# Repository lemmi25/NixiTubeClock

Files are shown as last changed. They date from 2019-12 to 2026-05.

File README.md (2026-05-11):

# ESP32 NixiTube OTA Clock

<p align="center">
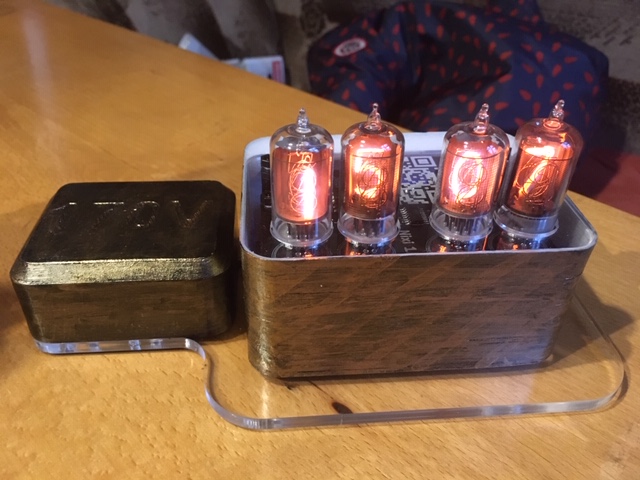
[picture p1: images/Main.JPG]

</p>

## Hardware Profiles

Firmware variants live in src/hardware:

- master_no_rtc.cpp
	- No RTC module
	- Time sync from internet API
	- FreeRTOS tasks (display/buttons and WiFi/OTA)
- rtc_local.cpp
	- DS1307 RTC module
	- Local time from RTC with optional internet sync
	- Power and menu button handling in single-loop runtime

## Tube Types

Tube mapping is selected in include/clock_variant_config.h via config.env:

- ZM1000
- IN4
- DA2000 (numitron)

## Main Configuration

All build-time options are read from config.env by extra_scripts/read_config_env.py.
Each key in config.env becomes a C/C++ define automatically.

Typical minimal setup:

```env
HARDWARE_PROFILE=RTC_LOCAL
TUBE_TYPE=ZM1000

ENABLE_OTA=1
OTA_IP=192.168.10.56
OTA_PASSWORD=nixiclock

WIFI_SSID=YOUR_WIFI_SSID
WIFI_PASSWORD=YOUR_WIFI_PASSWORD
CITY=Europe/Berlin
TIME_API_BASE=https://timeapi.io/api/Time/current/zone?timeZone=
```

## OTA Update

OTA is enabled with ENABLE_OTA=1.

- OTA stays always available after WiFi is connected.
- Flash command:

```bash
./scripts/ota_flash_monitor.sh
```

The script reads OTA_IP, OTA_PASSWORD, OTA_PORT from config.env, builds firmware, uploads over OTA, then opens serial monitor.

## Buttons And LEDs

Current runtime behavior:

- Power button (BTN_ON / GPIO3): toggle hibernate and wake
- Menu button (BTN_MODE / GPIO15): short/long press function handling
- LED brightness level: LED_DIM
	- master_no_rtc currently uses LED_DIM in firmware defaults
	- rtc_local supports LED_DIM from config.env and includes boot LED intro animation

## Build

USB build/upload:

```bash
platformio run -e esp-wrover-kit
```

OTA build/upload environment:

```bash
platformio run -e esp-wrover-kit-ota
```

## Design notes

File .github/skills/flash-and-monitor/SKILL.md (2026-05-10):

---
name: flash-and-monitor
description: 'Build, upload (flash), and monitor NixiTubeClock firmware via PlatformIO. Use when flashing firmware, selecting hardware profile or tube type from config.env, opening serial monitor, and debugging over USB.'
argument-hint: 'Optional: port override, e.g. --upload-port /dev/ttyUSB0'
---

# Flash & Monitor — NixiTubeClock

## When to Use
- Uploading new firmware to the ESP32 clock board
- Opening the serial monitor to watch boot logs or debug output
- Verifying a build before or after flashing
- Verifying the selected hardware profile and tube mapping from config.env

## Config First

Before build/flash, edit `config.env` (create from `config.env.example`):

```env
HARDWARE_PROFILE=MASTER_NO_RTC
TUBE_TYPE=ZM1000
PROVISION_AP_NAME=NixiClockSetup
WIFI_SYNC_SECONDS=3600
MAX_SYNC_FAILS=3
TIME_API_BASE=http://worldtimeapi.org/api/timezone
WIFI_SSID=YOUR_WIFI_SSID
WIFI_PASSWORD=YOUR_WIFI_PASSWORD
CITY=Europe/Berlin
```

**Note:** `TIME_API_BASE` uses a global base URL (no continent prefix). Your `CITY` setting must use "Continent/City" format like "Europe/Berlin", "America/New_York", or "Asia/Tokyo".

**Fast path:** if `FORCE_PROVISIONING=0` in `config.env` and the SSID/password above are valid, the firmware will skip the hotspot and connect directly to WiFi at boot.

## Prerequisites
- [PlatformIO Core](https://docs.platformio.org/en/latest/core/installation/index.html) installed (or use the PlatformIO IDE extension in VS Code)
- ESP32 board connected via USB
- Working directory: project root (where `platformio.ini` lives)

## Manual Boot Mode (Custom PCB)

This PCB has **no auto-reset circuit** (no DTR/RTS → BOOT/EN wiring).  
You must put the ESP32 into download mode manually before every flash:

1. Hold down the **BOOT** button
2. Press and release the **RST** button *(keep BOOT held)*
3. Release the **BOOT** button
4. ESP32 is now in download mode — run the upload command within a few seconds

> `platformio.ini` already has `--before no_reset` so esptool will not try to auto-reset.  
> The flash script (`scripts/flash_and_monitor.sh`) will prompt you to complete these steps before uploading.

## Commands

### 1. Build only
```sh
pio run -e esp-wrover-kit
```

### 2. Build + Upload (flash)
```sh
pio run -e esp-wrover-kit -t upload
```

### 3. Serial monitor (57600 baud, matches `monitor_speed` in platformio.ini)
```sh
pio device monitor --baud 115200
```

### 4. Build, upload, then immediately open serial monitor
```sh
pio run -e esp-wrover-kit -t upload && pio device monitor --baud 115200
```

## Port Troubleshooting

List all connected serial devices:
```sh
pio device list
```

Override the upload port manually:
```sh
pio run -e esp-wrover-kit -t upload --upload-port /dev/ttyUSB0
```

On Linux, if you get a **permission denied** error on the serial port:
```sh
sudo usermod -aG dialout $USER   # then log out and back in
```

## Expected Behavior by Hardware Profile

**MASTER_NO_RTC**
- Connects to WiFi and fetches time from `TIME_API_BASE` + `CITY`
- Displays hour/minute from internet response

**RTC_LOCAL**
- Reads time from DS1307 RTC
- Does not require internet time sync

## Error Conditions

| Serial output | Meaning | What happens next |
|---|---|---|
| `config.env loaded ...` | Build script parsed config values | Confirms selected hardware and tube |
| `Unknown HARDWARE_PROFILE=...` | Invalid profile value in config.env | Build uses no valid profile and fails at compile guard |
| `Unknown TUBE_TYPE=...` | Invalid tube selection in config.env | Build has no matching tube mapping |

See the `debug-clock-hardware` skill for full hardware diagnostics.

## Key Files
- [platformio.ini](../../../platformio.ini) — build environment, script integration, source filter
- [config.env.example](../../../config.env.example) — template for local config
- [extra_scripts/read_config_env.py](../../../extra_scripts/read_config_env.py) — config.env parser
- [src/hardware/master_no_rtc.cpp](../../../src/hardware/master_no_rtc.cpp) — no RTC profile
- [src/hardware/rtc_local.cpp](../../../src/hardware/rtc_local.cpp) — RTC profile

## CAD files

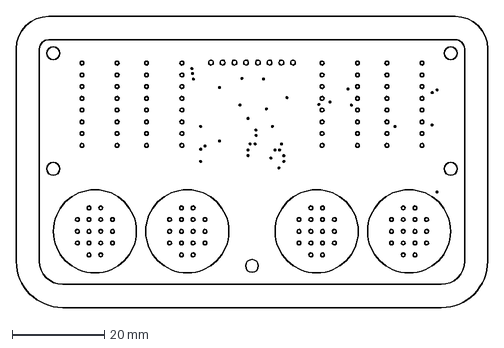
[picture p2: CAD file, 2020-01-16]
Case/nixiTop.dxf
102.0 x 63.0 mm

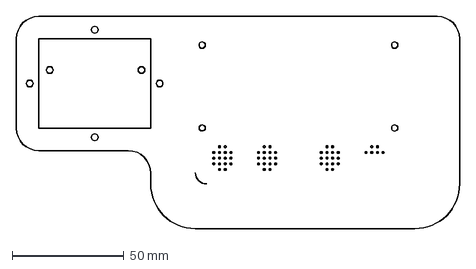
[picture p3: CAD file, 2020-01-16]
Case/nixiBottom.dxf
198.0 x 94.9 mm

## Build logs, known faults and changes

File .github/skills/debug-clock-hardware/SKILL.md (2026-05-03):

---
name: debug-clock-hardware
description: 'Debug all NixiTubeClock hardware variants and modules: no-RTC and RTC profiles, tube mappings (ZM1000/IN4/DA2000), WiFi provisioning AP, shift-register output, RTC wiring, and display behavior.'
argument-hint: 'Optional: describe symptom, e.g. "setup AP not visible", "digits swapped", "RTC loses time", or "wrong tube output"'
---

# Debug Clock Hardware - NixiTubeClock

## When to Use
- Setup hotspot is not visible or web portal does not open
- WiFi credentials are saved but internet sync still fails
- RTC profile does not keep time between sync cycles
- No-RTC profile drifts or stops updating time
- Digits appear swapped or incorrect for your tube type
- DA2000 numitron output is wrong while nixie tubes work
- Display is blank or only partial digits are lit

## Hardware Profiles

Configured in `config.env`:

| Key | Values | Behavior |
|---|---|---|
| `HARDWARE_PROFILE` | `MASTER_NO_RTC`, `RTC_LOCAL` | Selects no-RTC or RTC firmware path |
| `TUBE_TYPE` | `ZM1000`, `IN4`, `DA2000` | Selects segment mapping and numitron mode |

Relevant files:
- [src/hardware/master_no_rtc.cpp](../../../src/hardware/master_no_rtc.cpp)
- [src/hardware/rtc_local.cpp](../../../src/hardware/rtc_local.cpp)
- [include/clock_variant_config.h](../../../include/clock_variant_config.h)
- [src/nixiDriver.cpp](../../../src/nixiDriver.cpp)

## Provisioning AP and Web Portal Checks

Provisioning implementation:
- [src/hardware/clock_provisioning.cpp](../../../src/hardware/clock_provisioning.cpp)
- [include/clock_provisioning.h](../../../include/clock_provisioning.h)

Expected behavior:
1. If config is missing/invalid, ESP opens AP (`PROVISION_AP_NAME`)
2. Connect to AP and open `http://192.168.4.1`
3. Save `ssid`, `password`, `city`
4. Device restarts and uses saved settings

If AP is not visible:
- Verify `PROVISION_AP_NAME` in `config.env`
- Ensure placeholders are not left as real credentials
- Check monitor output for `Entering provisioning mode` and `AP IP`

## RTC Path Diagnostics (`RTC_LOCAL`)

- Confirm DS1307 wiring and I2C lines
- Confirm backup battery polarity and charge
- Verify `rtc.begin()` and `rtc.isrunning()` path at boot
- If internet sync fails repeatedly, device should re-enter provisioning mode

## No-RTC Path Diagnostics (`MASTER_NO_RTC`)

- Device syncs internet time every `WIFI_SYNC_SECONDS` (default 3600)
- Between syncs, display time uses internal millis-based counter
- If sync fails `MAX_SYNC_FAILS` times, provisioning portal should open

## Tube Mapping Diagnostics

Mappings live in:
- [include/clock_variant_config.h](../../../include/clock_variant_config.h)

Quick checks:
- `ZM1000`: straight mapping 1-2-3-4
- `IN4`: swapped first two segments
- `DA2000`: reverse segment ordering and numitron logic

If digits are wrong:
1. Confirm `TUBE_TYPE` in `config.env`
2. Rebuild and verify build output shows selected type
3. If still wrong, check wiring from shift register outputs to tube drivers

## Build/Config Validation Checklist

1. Confirm `config.env` exists and is parsed
2. Confirm `HARDWARE_PROFILE` and `TUBE_TYPE` are valid
3. Confirm pre-script is enabled in `platformio.ini`
4. Rebuild after config changes (`clean` + build)

## Key Files
- [config.env.example](../../../config.env.example)
- [config.env](../../../config.env)
- [platformio.ini](../../../platformio.ini)
- [extra_scripts/read_config_env.py](../../../extra_scripts/read_config_env.py)
- [src/hardware/hardware_profile_guard.cpp](../../../src/hardware/hardware_profile_guard.cpp)

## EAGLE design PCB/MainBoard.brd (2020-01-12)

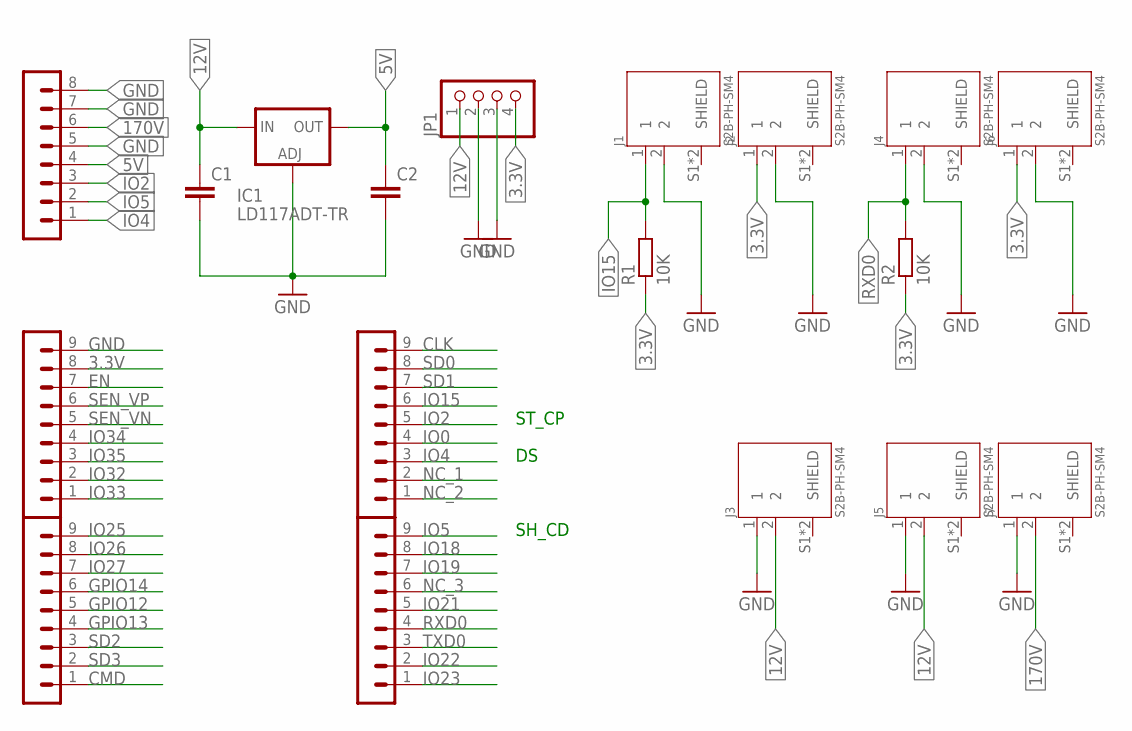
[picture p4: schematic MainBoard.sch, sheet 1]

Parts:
C1, C2: C-EU_1206C1206; C1206
IC1: LD117ADT-TR; DPACK
J1, J2, J3, J4, J5, J6, J7: S2B-PH-SM4; JST_S2B-PH-SM4-TB(LF)(SN)
JP1: PINHD-1X4; 1X04
R1, R2: 10K; R1206
SV1: PINHEADER-1X8; MA08-1
SV2, SV3, SV4, SV5: PINHEADER-1X9; MA09-1

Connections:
3.3V: J2.1, J6.1, JP1.4, R1.1, R2.1, SV2.8
5V: C2.1, IC1.4 (OUT), SV1.4
12V: C1.1, IC1.3 (IN), J3.2, J5.2, JP1.1
170V: J7.2, SV1.6
CLK: SV4.9
CMD: SV3.1
EN: SV2.7
GND: C1.2, C2.2, IC1.1 (ADJ), J1.2, J2.2, J3.1, J4.2, J5.1, J6.2, J7.1, JP1.2, JP1.3, SV1.5, SV1.7, SV1.8, SV2.9
GPIO12: SV3.5
GPIO13: SV3.4
GPIO14: SV3.6
IO0: SV4.4
IO2: SV1.3, SV4.5
IO4: SV1.1, SV4.3
IO5: SV1.2, SV5.9
IO15: J1.1, R1.2, SV4.6
IO18: SV5.8
IO19: SV5.7
IO21: SV5.5
IO22: SV5.2
IO23: SV5.1
IO25: SV3.9
IO26: SV3.8
IO27: SV3.7
IO32: SV2.2
IO33: SV2.1
IO34: SV2.4
IO35: SV2.3
NC_1: SV4.2
NC_2: SV4.1
NC_3: SV5.6
RXD0: J4.1, R2.2, SV5.4
SD0: SV4.8
SD1: SV4.7
SD2: SV3.3
SD3: SV3.2
SEN_VN: SV2.5
SEN_VP: SV2.6
TXD0: SV5.3

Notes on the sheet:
ST_CP
SH_CD

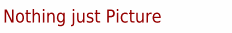
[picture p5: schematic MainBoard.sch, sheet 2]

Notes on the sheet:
Nothing just Picture


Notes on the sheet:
Nothing just Picture

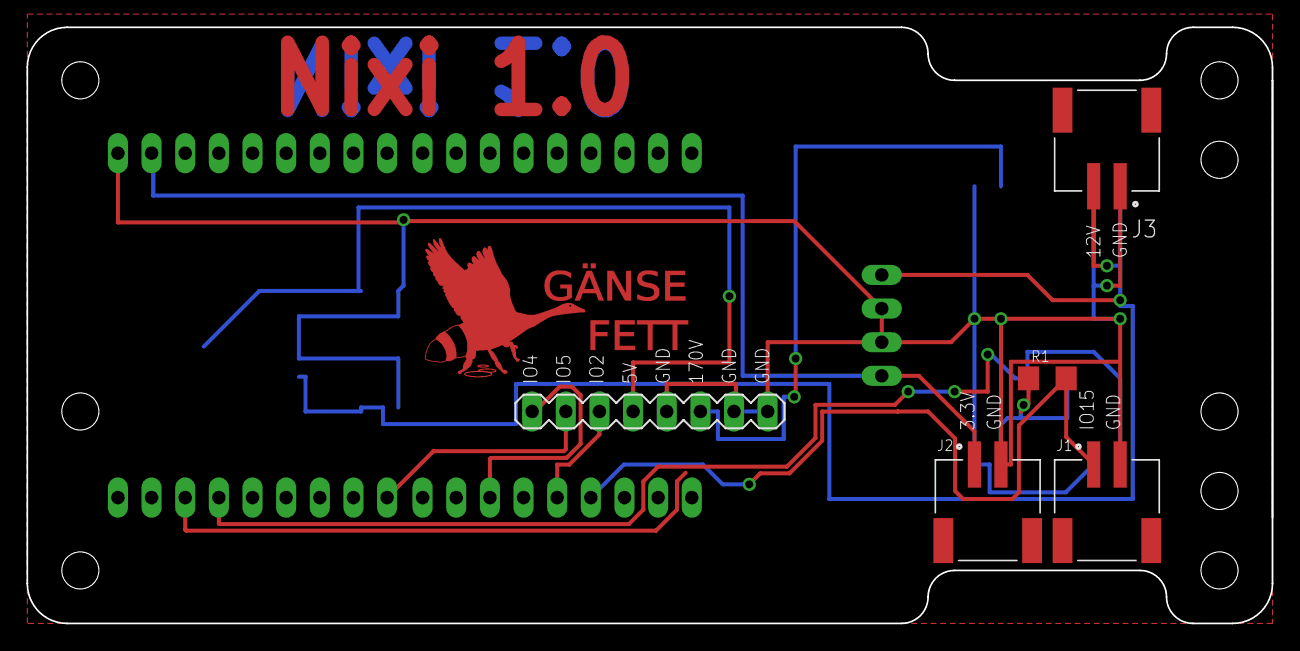
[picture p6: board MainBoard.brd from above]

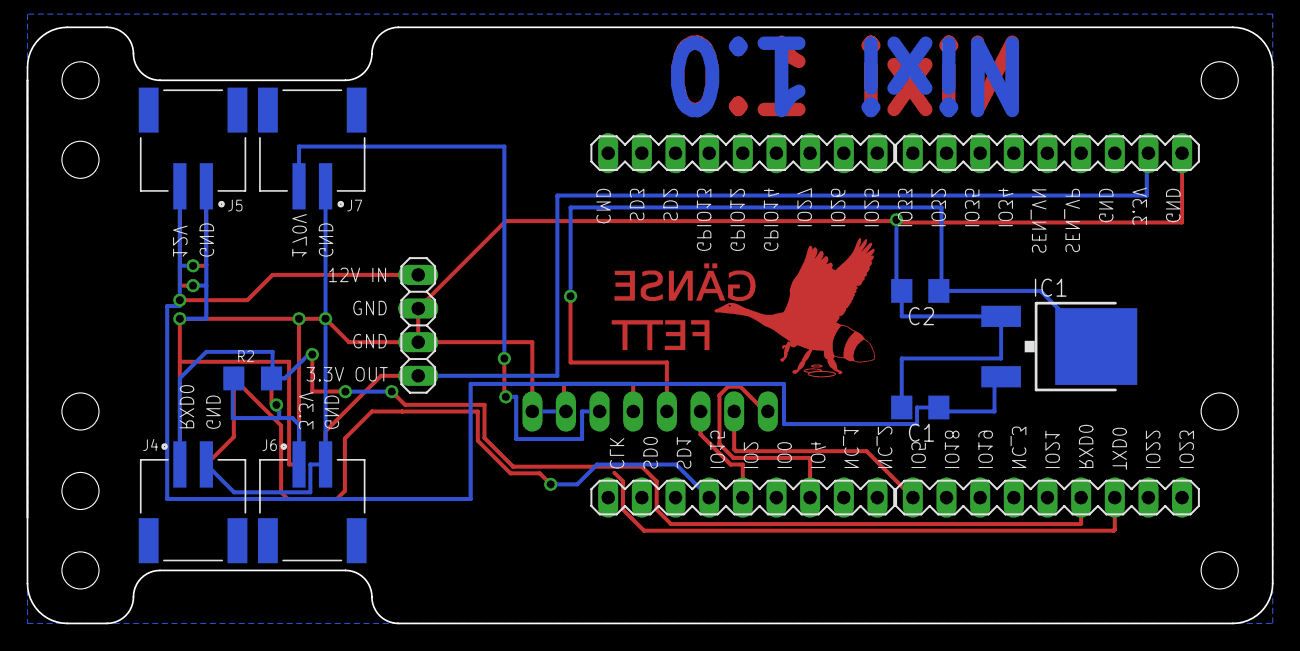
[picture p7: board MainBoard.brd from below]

Board: 2 copper layers, 94.0 x 45.0 mm, 18 parts (13 on the bottom side), 10 nets.

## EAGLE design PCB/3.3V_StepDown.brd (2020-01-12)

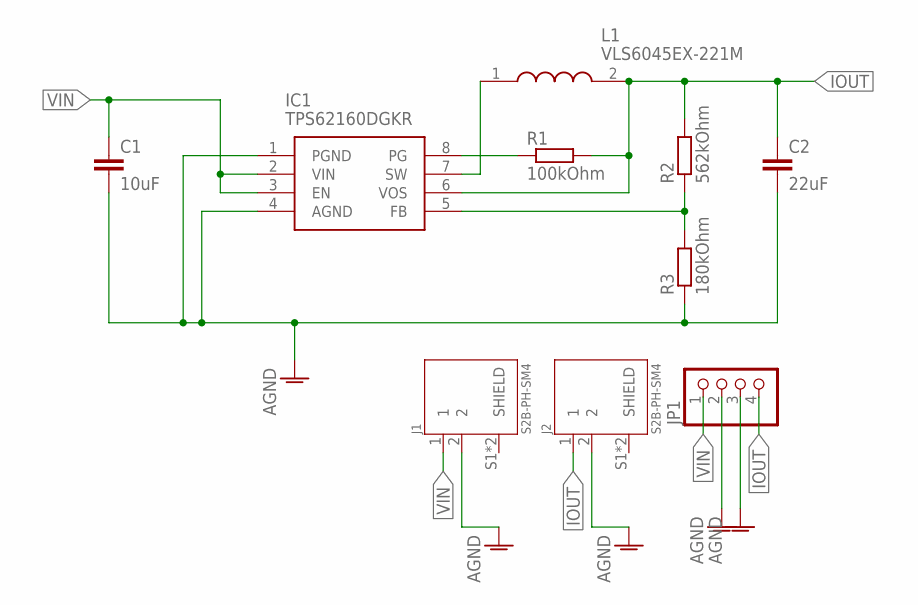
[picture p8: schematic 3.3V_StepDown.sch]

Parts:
C1: 10uF; C1206
C2: 22uF; C0805K
IC1: TPS62160DGKR; SOP65P490X110-8N
J1, J2: S2B-PH-SM4; JST_S2B-PH-SM4-TB(LF)(SN)
JP1: PINHD-1X4; 1X04
L1: VLS6045EX-221M; INDPM6060X450N
R1: 100kOhm; R1206
R2: 562kOhm; R0805
R3: 180kOhm; R0402

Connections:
AGND: C1.2, C2.2, IC1.1 (PGND), IC1.4 (AGND), J1.2, J2.2, JP1.2, JP1.3, R3.1
FB2: IC1.5 (FB), R2.1, R3.2
IOUT: C2.1, IC1.6 (VOS), J2.1, JP1.4, L1.2, R1.2, R2.2
PG2: IC1.8 (PG), R1.1
SW2: IC1.7 (SW), L1.1
VIN: C1.1, IC1.2 (VIN), IC1.3 (EN), J1.1, JP1.1

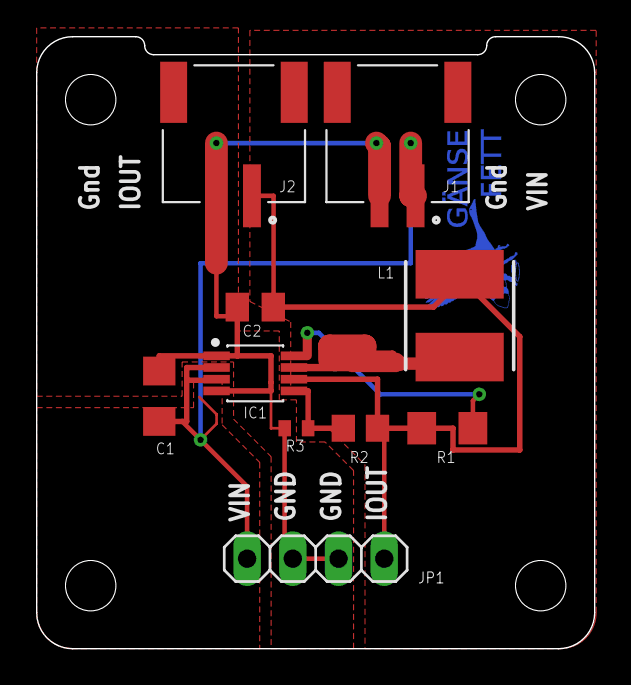
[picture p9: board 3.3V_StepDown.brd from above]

Board: 2 copper layers, 31.0 x 34.0 mm, 10 parts (0 on the bottom side), 6 nets.

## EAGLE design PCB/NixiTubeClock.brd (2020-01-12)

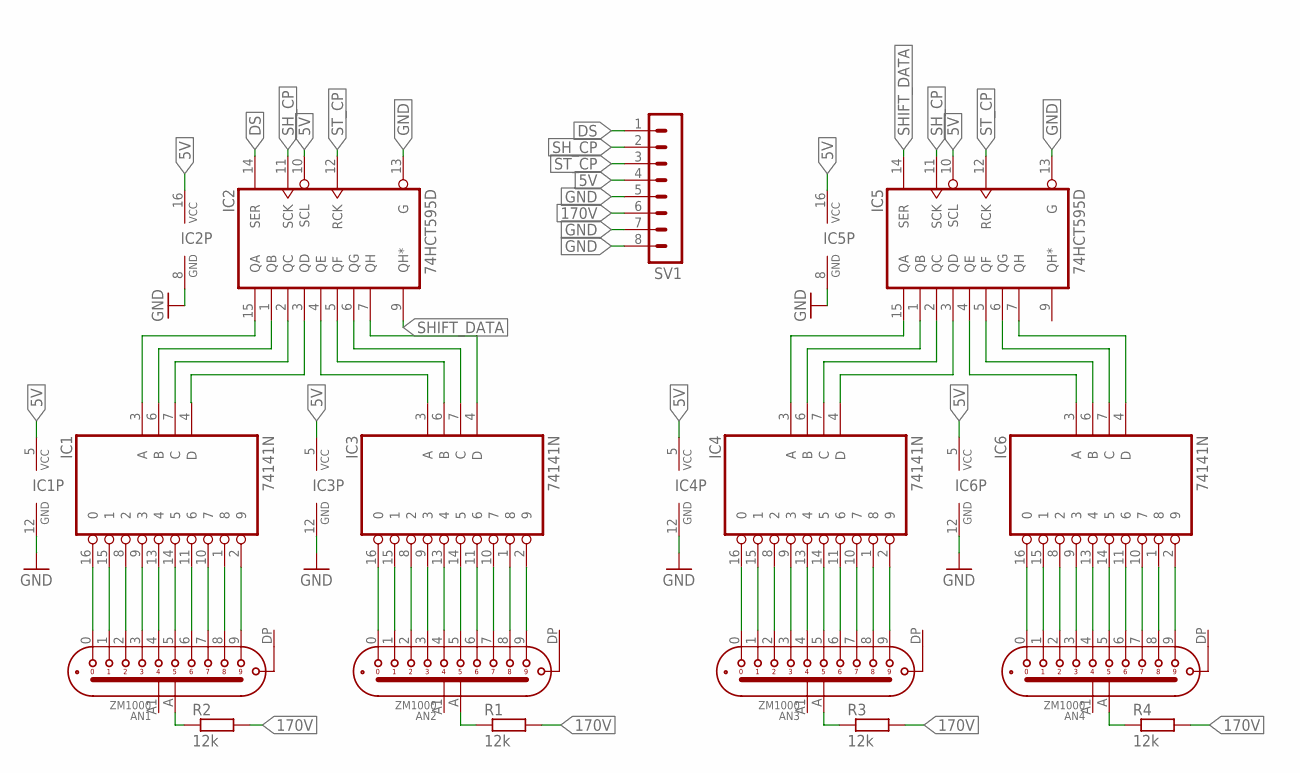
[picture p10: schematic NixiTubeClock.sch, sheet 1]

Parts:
AN1, AN2, AN3, AN4: ZM1000
IC1, IC3, IC4, IC6: 74141N; DIL16
IC2, IC5: 74HCT595D; SO16
R1, R2, R3, R4: 12k; R1206
SV1: MA08-1

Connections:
5V: IC1.5 (VCC), IC2.10 (SCL), IC2.16 (VCC), IC3.5 (VCC), IC4.5 (VCC), IC5.10 (SCL), IC5.16 (VCC), IC6.5 (VCC), SV1.4
170V: R1.2, R2.2, R3.2, R4.2, SV1.6
DS: IC2.14 (SER), SV1.1
GND: IC1.12 (GND), IC2.8 (GND), IC2.13 (G), IC3.12 (GND), IC4.12 (GND), IC5.8 (GND), IC5.13 (G), IC6.12 (GND), SV1.5, SV1.7, SV1.8
unnamed: IC4.4 (D), IC5.3 (QD)
unnamed: AN1.0, IC1.16 (0)
unnamed: AN1.1, IC1.15 (1)
unnamed: AN1.2, IC1.8 (2)
unnamed: AN1.3, IC1.9 (3)
unnamed: AN1.4, IC1.13 (4)
unnamed: AN1.5, IC1.14 (5)
unnamed: AN1.6, IC1.11 (6)
unnamed: AN1.7, IC1.10 (7)
unnamed: AN1.8, IC1.1 (8)
unnamed: AN1.9, IC1.2 (9)
unnamed: AN2.0, IC3.16 (0)
unnamed: AN2.1, IC3.15 (1)
unnamed: AN2.2, IC3.8 (2)
unnamed: AN2.3, IC3.9 (3)
unnamed: AN2.4, IC3.13 (4)
unnamed: AN2.5, IC3.14 (5)
unnamed: AN2.6, IC3.11 (6)
unnamed: AN2.7, IC3.10 (7)
unnamed: AN2.8, IC3.1 (8)
unnamed: AN2.9, IC3.2 (9)
unnamed: AN3.0, IC4.16 (0)
unnamed: AN3.1, IC4.15 (1)
unnamed: AN3.2, IC4.8 (2)
unnamed: AN3.3, IC4.9 (3)
unnamed: AN3.4, IC4.13 (4)
unnamed: AN3.5, IC4.14 (5)
unnamed: AN3.6, IC4.11 (6)
unnamed: AN3.7, IC4.10 (7)
unnamed: AN3.8, IC4.1 (8)
unnamed: AN3.9, IC4.2 (9)
unnamed: AN4.0, IC6.16 (0)
unnamed: AN4.1, IC6.15 (1)
unnamed: AN4.2, IC6.8 (2)
unnamed: AN4.3, IC6.9 (3)
unnamed: AN4.4, IC6.13 (4)
unnamed: AN4.5, IC6.14 (5)
unnamed: AN4.6, IC6.11 (6)
unnamed: AN4.7, IC6.10 (7)
unnamed: AN4.8, IC6.1 (8)
unnamed: AN4.9, IC6.2 (9)
unnamed: AN1.A (A1), R2.1
unnamed: AN2.A (A1), R1.1
unnamed: AN3.A (A1), R3.1
unnamed: AN4.A (A1), R4.1
unnamed: IC1.3 (A), IC2.15 (QA)
unnamed: IC1.6 (B), IC2.1 (QB)
unnamed: IC1.7 (C), IC2.2 (QC)
unnamed: IC1.4 (D), IC2.3 (QD)
unnamed: IC2.4 (QE), IC3.3 (A)
unnamed: IC2.5 (QF), IC3.6 (B)
unnamed: IC2.6 (QG), IC3.7 (C)
unnamed: IC2.7 (QH), IC3.4 (D)
unnamed: IC4.3 (A), IC5.15 (QA)
unnamed: IC4.6 (B), IC5.1 (QB)
unnamed: IC4.7 (C), IC5.2 (QC)
unnamed: IC5.4 (QE), IC6.3 (A)
unnamed: IC5.5 (QF), IC6.6 (B)
unnamed: IC5.6 (QG), IC6.7 (C)
unnamed: IC5.7 (QH), IC6.4 (D)
SHIFT_DATA: IC2.9 (QH*), IC5.14 (SER)
SH_CP: IC2.11 (SCK), IC5.11 (SCK), SV1.2
ST_CP: IC2.12 (RCK), IC5.12 (RCK), SV1.3


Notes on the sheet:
Nothing just Picture

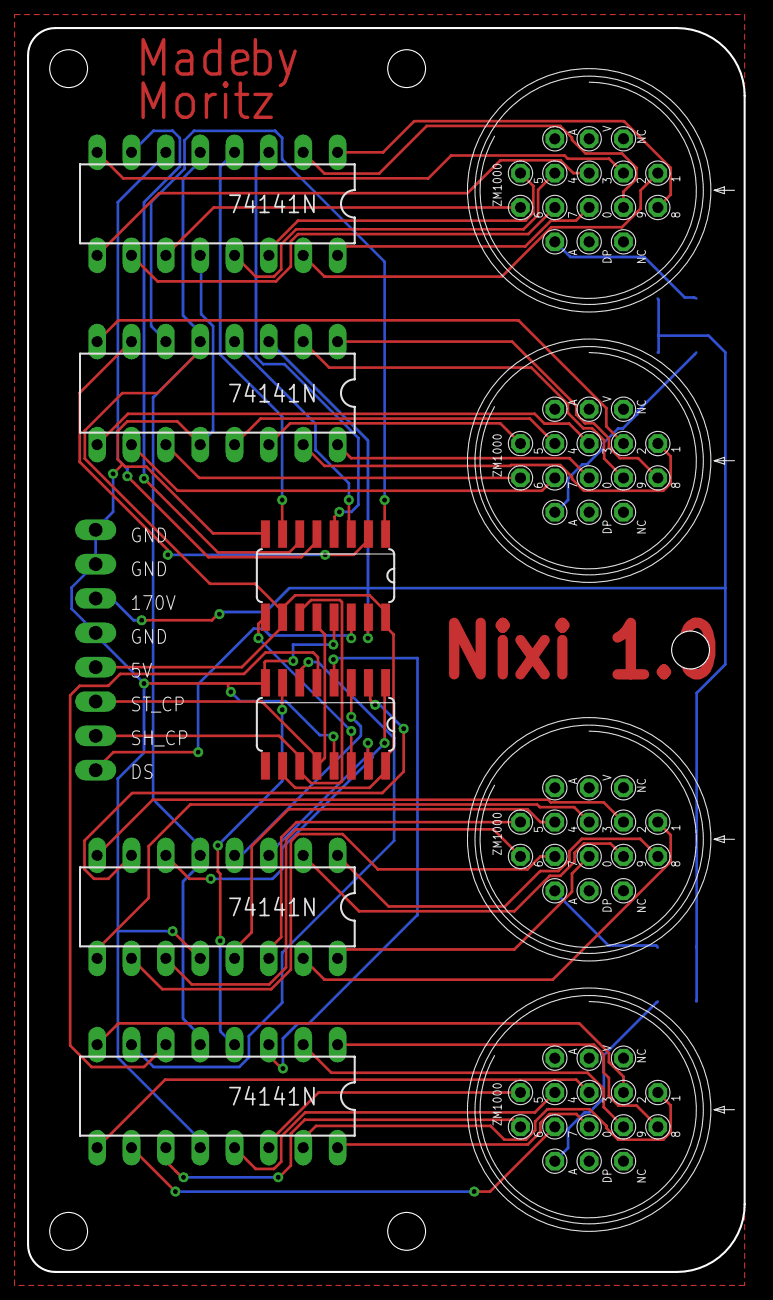
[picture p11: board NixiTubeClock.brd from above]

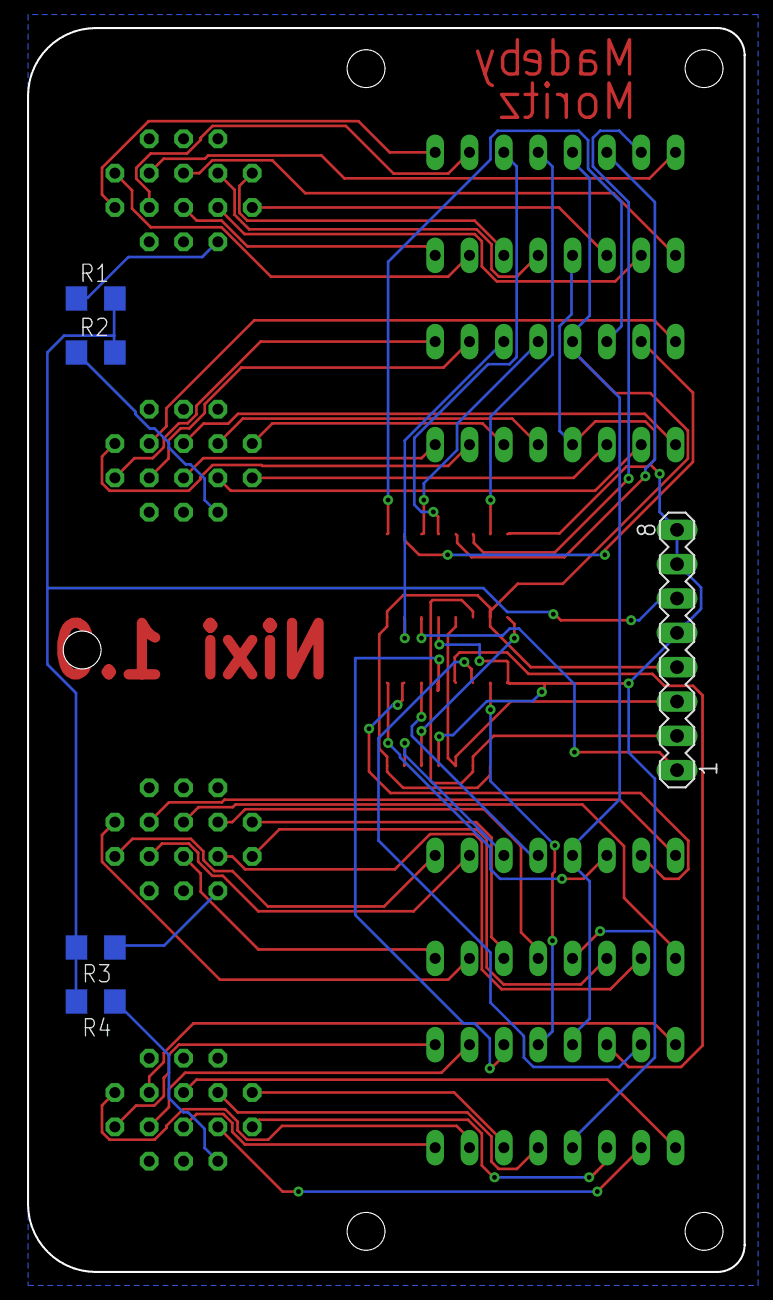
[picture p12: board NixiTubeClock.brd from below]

Board: 2 copper layers, 53.0 x 92.0 mm, 15 parts (5 on the bottom side), 67 nets.

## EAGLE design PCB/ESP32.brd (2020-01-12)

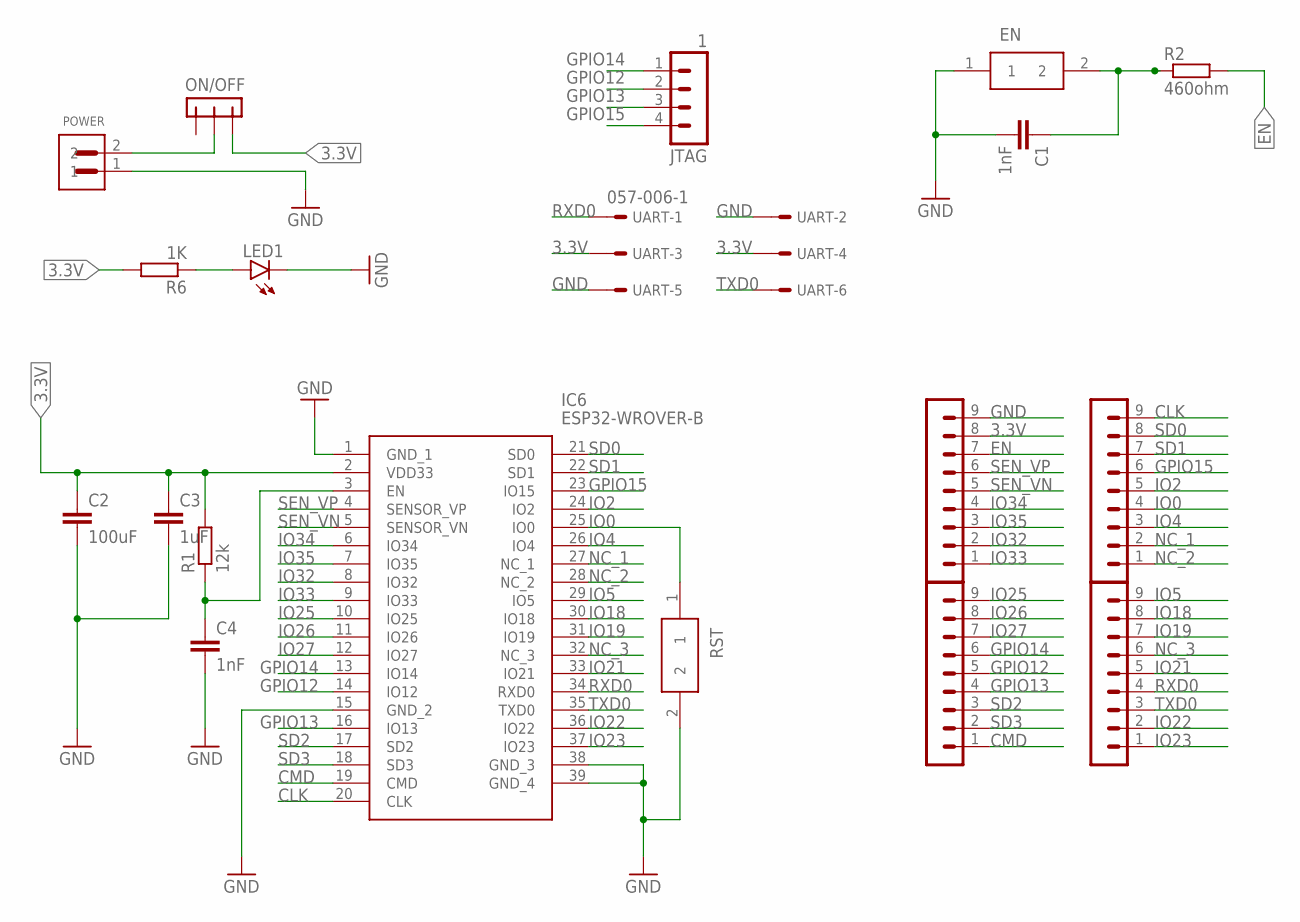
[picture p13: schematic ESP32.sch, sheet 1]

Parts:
C1, C4: 1nF; C0805
C2: 100uF; C1206
C3: 1uF; C0805
EN: FSMSMTR; FSMSM
IC6: ESP32-WROVER-B; ESP32WROVERIB16MB
JTAG: 1; MA04-1
LED1: LEDSMT1206; 1206
ON/OFF: -CON3; CON3
POWER: S2B-PH-SM4-TB; JST_S2B-PH-SM4-TB
R1: 12k; R0805
R2: 460ohm; R0805
R6: 1K; R1206
RST: FSMSMTR; FSMSM
SV1, SV2, SV5, SV6: PINHEADER-1X9; MA09-1
UART: 057-006-1

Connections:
3.3V: C2.1, C3.1, IC6.2 (VDD33), ON/OFF.P$1 (1), R1.2, R6.2, SV5.8, UART.3, UART.4
CLK: IC6.20 (CLK), SV1.9
CMD: IC6.19 (CMD), SV6.1
EN: C1.1, C4.1, EN.2, IC6.3 (EN), R1.1, R2.1, R2.2, SV5.7
GND: C1.2, C2.2, C3.2, C4.2, EN.1, IC6.1 (GND_1), IC6.15 (GND_2), IC6.38 (GND_3), IC6.39 (GND_4), LED1.C, POWER.1, RST.2, SV5.9, UART.2, UART.5
GPIO12: IC6.14 (IO12), JTAG.2, SV6.5
GPIO13: IC6.16 (IO13), JTAG.3, SV6.4
GPIO14: IC6.13 (IO14), JTAG.1, SV6.6
GPIO15: IC6.23 (IO15), JTAG.4, SV1.6
IO0: IC6.25 (IO0), RST.1, SV1.4
IO2: IC6.24 (IO2), SV1.5
IO4: IC6.26 (IO4), SV1.3
IO5: IC6.29 (IO5), SV2.9
IO18: IC6.30 (IO18), SV2.8
IO19: IC6.31 (IO19), SV2.7
IO21: IC6.33 (IO21), SV2.5
IO22: IC6.36 (IO22), SV2.2
IO23: IC6.37 (IO23), SV2.1
IO25: IC6.10 (IO25), SV6.9
IO26: IC6.11 (IO26), SV6.8
IO27: IC6.12 (IO27), SV6.7
IO32: IC6.8 (IO32), SV5.2
IO33: IC6.9 (IO33), SV5.1
IO34: IC6.6 (IO34), SV5.4
IO35: IC6.7 (IO35), SV5.3
unnamed: ON/OFF.P$2 (2), POWER.2
unnamed: LED1.A, R6.1
NC_1: IC6.27 (NC_1), SV1.2
NC_2: IC6.28 (NC_2), SV1.1
NC_3: IC6.32 (NC_3), SV2.6
RXD0: IC6.34 (RXD0), SV2.4, UART.1
SD0: IC6.21 (SD0), SV1.8
SD1: IC6.22 (SD1), SV1.7
SD2: IC6.17 (SD2), SV6.3
SD3: IC6.18 (SD3), SV6.2
SEN_VN: IC6.5 (SENSOR_VN), SV5.5
SEN_VP: IC6.4 (SENSOR_VP), SV5.6
TXD0: IC6.35 (TXD0), SV2.3, UART.6

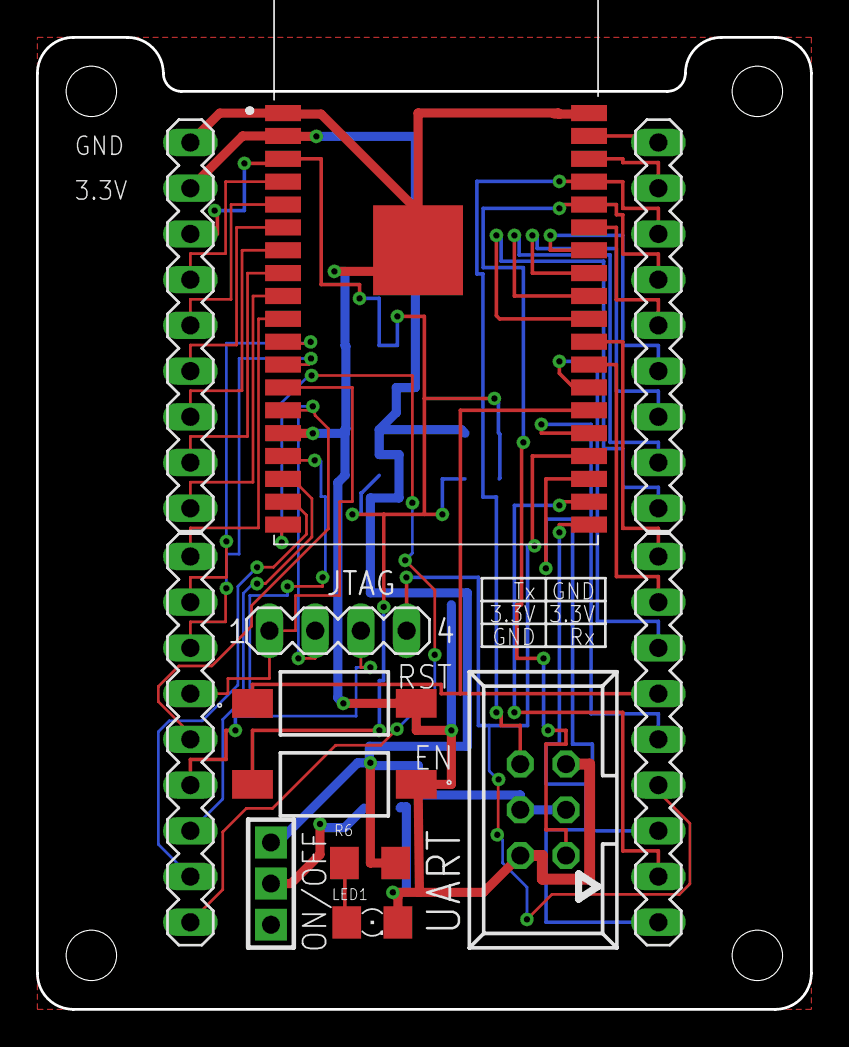
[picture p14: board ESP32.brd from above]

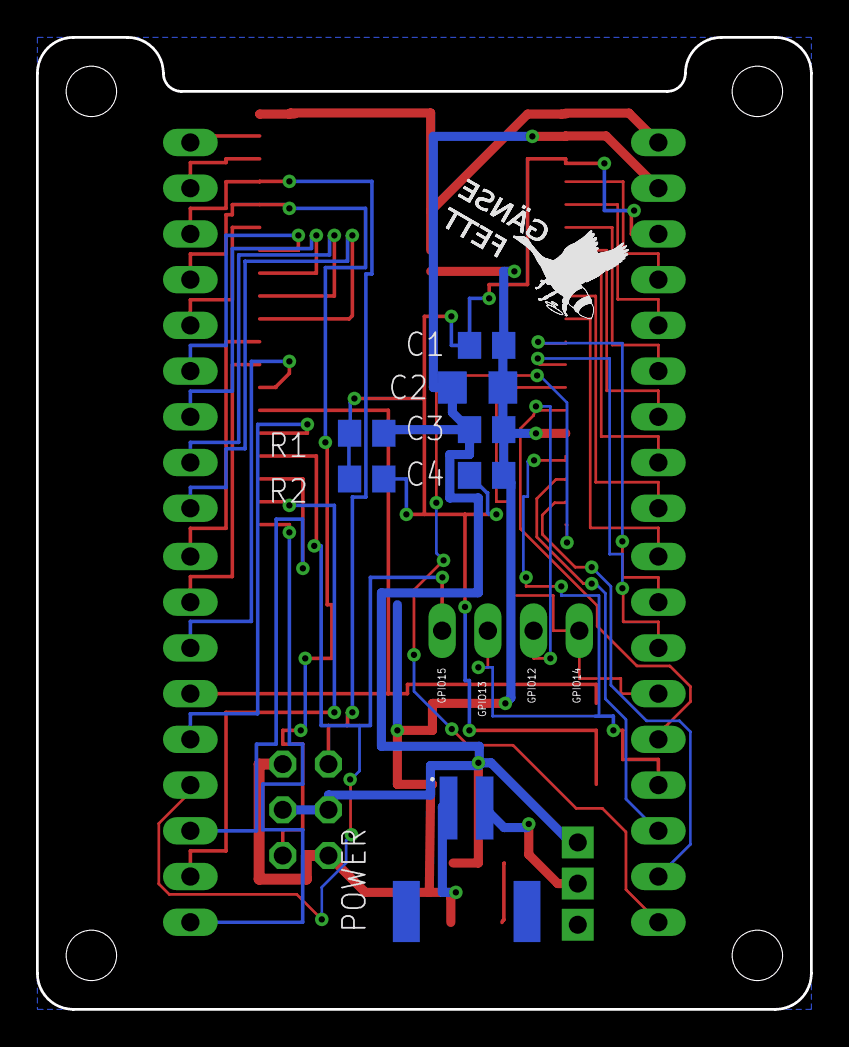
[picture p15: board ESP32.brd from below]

Board: 2 copper layers, 43.0 x 54.0 mm, 19 parts (7 on the bottom side), 38 nets.

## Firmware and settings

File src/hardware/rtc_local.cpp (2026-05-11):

/* Hardware profile: rtc_local
 * - RTC module present
 * - Time is read locally from RTC (no internet time sync)
 */

#if defined(HARDWARE_RTC_LOCAL)

#include <Arduino.h>
#include "RTClib.h"
#include <WiFi.h>
#include <HTTPClient.h>
#include <WiFiClientSecure.h>
#include <ArduinoJson.h>
#include <ArduinoOTA.h>
#include <nixiDriver.h>
#include <clock_variant_config.h>
#include <clock_provisioning.h>

#ifndef ENABLE_TEMP_SENSOR
#define ENABLE_TEMP_SENSOR 0
#endif

#if ENABLE_TEMP_SENSOR
#include <SHT21.h>
static SHT21 tempSensor;
#endif

#ifndef WIFI_SYNC_SECONDS
#define WIFI_SYNC_SECONDS 3600
#endif

#ifndef ENABLE_OTA
#define ENABLE_OTA 0
#endif

#ifndef OTA_HOSTNAME
#define OTA_HOSTNAME "NixiClock"
#endif

#ifndef PROVISION_ON_CONNECT_FAIL
#define PROVISION_ON_CONNECT_FAIL 1
#endif

#define BTN_ON_PIN 3  // Power/sleep button (active LOW, shared with UART RX)
#define BTN_MODE_PIN 15 // Menu button (active LOW, pull-up)
#define LED_RED_PIN   27
#define LED_WHITE_PIN 26
#define LED_RED_CH    0
#define LED_WHITE_CH  1
#define LED_PWM_FREQ  150000
#define LED_PWM_BITS  10
// 10-bit PWM full-scale duty.
#define LED_MAX       1023
#define LED_DIM       70


RTC_DS1307 rtc;
nixiDriver ClockDisplay(4, 5, 2, CLOCK_IS_NUMITRON);
HTTPClient http;
StaticJsonDocument<2048> doc;
ClockConfig g_config;

unsigned long lastSyncMs = 0;
bool otaInitialized = false;

const unsigned long syncIntervalMs = WIFI_SYNC_SECONDS * 1000UL;

enum PowerState { POWER_AWAKE, POWER_HIBERNATE };
static PowerState g_powerState = POWER_AWAKE;

static void ledFade(int from, int to, int stepDelayMs)
{
  if (from <= to)
  {
    for (int i = from; i <= to; i++)
    {
      ledcWrite(LED_WHITE_CH, i);
      ledcWrite(LED_RED_CH, i);
      delay(stepDelayMs);
    }
  }
  else
  {
    for (int i = from; i >= to; i--)
    {
      ledcWrite(LED_WHITE_CH, i);
      ledcWrite(LED_RED_CH, i);
      delay(stepDelayMs);
    }
  }
}

static void showHourMinute(uint8_t hour, uint8_t minute)
{
  ClockDisplay.writeSegment(hour / 10, SEGMENT_1);
  ClockDisplay.writeSegment(hour % 10, SEGMENT_2);
  ClockDisplay.writeSegment(minute / 10, SEGMENT_3);
  ClockDisplay.writeSegment(minute % 10, SEGMENT_4);
}

static void runStopwatch()
{
  uint32_t sec = 0;
  unsigned long lastTickMs = millis();
  // When false, stopwatch value is frozen on the display until power exits.
  bool stopwatchRunning = true;

  for (;;)
  {
    const unsigned long nowMs = millis();
    const bool modePressed = (digitalRead(BTN_MODE_PIN) == LOW);
    const bool powerPressed = (digitalRead(BTN_ON_PIN) == LOW);

    const uint8_t m = (uint8_t)(sec / 60U);
    const uint8_t s = (uint8_t)(sec % 60U);
    if (m >= 60)
    {
      break;
    }

    showHourMinute(m, s);

    // Menu press freezes stopwatch at the current value.
    if (modePressed && stopwatchRunning)
    {
      delay(20);
      if (digitalRead(BTN_MODE_PIN) == LOW)
      {
        // Menu press: stop stopwatch and keep showing the stopped time.
        while (digitalRead(BTN_MODE_PIN) == LOW)
        {
          delay(20);
        }
        stopwatchRunning = false;
      }
    }

    // Power press leaves stopwatch and returns to normal clock mode.
    if (powerPressed)
    {
      delay(20);
      if (digitalRead(BTN_ON_PIN) == LOW)
      {
        // Power press: leave stopwatch and return to normal clock time.
        while (digitalRead(BTN_ON_PIN) == LOW)
        {
          delay(20);
        }
        return;
      }
    }

    if (stopwatchRunning && nowMs - lastTickMs >= 1000)
    {
      lastTickMs += 1000;
      sec++;
    }

    delay(20);
  }
}

#if ENABLE_TEMP_SENSOR
static void showSensorDisplay()
{
  const float rawT = tempSensor.getTemperature();
  const float rawH = tempSensor.getHumidity();
  const int8_t t = (int8_t)(rawT >= 0 ? rawT + 0.5f : rawT - 0.5f);
  const uint8_t h = (uint8_t)(rawH + 0.5f);
  const uint8_t at = (uint8_t)(t < 0 ? -t : t);

  ClockDisplay.writeSegment(t < 0 ? 0 : 10, SEGMENT_1);
  ClockDisplay.writeSegment(t < 0 ? 0 : 10, SEGMENT_2);
  ClockDisplay.writeSegment(at / 10, SEGMENT_3);
  ClockDisplay.writeSegment(at % 10, SEGMENT_4);
  delay(1500);

  ClockDisplay.writeSegment(10, SEGMENT_1);
  ClockDisplay.writeSegment(10, SEGMENT_2);
  ClockDisplay.writeSegment(h / 10, SEGMENT_3);
  ClockDisplay.writeSegment(h % 10, SEGMENT_4);
  delay(1500);

  Serial.printf("[SENSOR] Temp: %d C  Humidity: %u%%\n", t, h);
}
#endif

static bool isOtaWindowActive()
{
#if ENABLE_OTA
  return otaInitialized;
#else
  return false;
#endif
}

static bool connectWifiForOta(uint32_t timeoutMs)
{
  if (WiFi.status() == WL_CONNECTED)
  {
    return true;
  }

  WiFi.mode(WIFI_STA);
  if (!applyStaNetworkConfig())
  {
    return false;
  }
  WiFi.begin(g_config.ssid.c_str(), g_config.password.c_str());

  const unsigned long started = millis();
  while (millis() - started < timeoutMs)
  {
    if (WiFi.status() == WL_CONNECTED)
    {
      return true;
    }
    delay(250);
  }

  return false;
}

static void setupOtaWindow()
{
#if ENABLE_OTA
  if (!connectWifiForOta(15000))
  {
    Serial.println("OTA disabled for this boot: WiFi connect failed");
    return;
  }

  ArduinoOTA.setHostname(OTA_HOSTNAME);
  ArduinoOTA.onStart([]() {
    Serial.println("OTA update started");
  });
  ArduinoOTA.onEnd([]() {
    Serial.println("OTA update finished");
  });
  ArduinoOTA.onError([](ota_error_t error) {
    Serial.print("OTA error: ");
    Serial.println((int)error);
  });
  ArduinoOTA.begin();
  otaInitialized = true;
  Serial.print("OTA ready at ");
  Serial.print(WiFi.localIP());
  Serial.println(" (always on)");
#endif
}

static void handleOta()
{
#if ENABLE_OTA
  if (!otaInitialized)
  {
    return;
  }

  ArduinoOTA.handle();
#endif
}

static bool syncRtcFromInternet()
{
  if (!connectConfiguredWifi(g_config, 15000))
  {
    return false;
  }

  const String url = buildTimeApiUrlForCity(g_config.city);
  WiFiClientSecure secureClient;
  secureClient.setInsecure();
  http.begin(secureClient, url);
  const int httpCode = http.GET();

  if (httpCode <= 0)
  {
    http.end();
    return false;
  }

  const String payload = http.getString();
  http.end();

  DeserializationError error = deserializeJson(doc, payload);
  if (error)
  {
    return false;
  }

  const char *date = doc["datetime"];
  if (date == nullptr)
  {
    date = doc["dateTime"];
  }
  if (date == nullptr)
  {
    return false;
  }

  const uint16_t year = (date[0] - '0') * 1000 + (date[1] - '0') * 100 + (date[2] - '0') * 10 + (date[3] - '0');
  const uint8_t month = (date[5] - '0') * 10 + (date[6] - '0');
  const uint8_t day = (date[8] - '0') * 10 + (date[9] - '0');
  const uint8_t hour = (date[11] - '0') * 10 + (date[12] - '0');
  const uint8_t minute = (date[14] - '0') * 10 + (date[15] - '0');
  const uint8_t second = (date[17] - '0') * 10 + (date[18] - '0');

  rtc.adjust(DateTime(year, month, day, hour, minute, second));

  Serial.printf("[SYNC] API time: %04u-%02u-%02u %02u:%02u:%02u -> RTC updated\n",
                year, month, day, hour, minute, second);

#if ENABLE_TEMP_SENSOR
  float tempC = tempSensor.getTemperature();
  float humidity = tempSensor.getHumidity();
  Serial.printf("[SENSOR] Temp: %.1f C  Humidity: %.1f%%\n", tempC, humidity);
#endif

  if (!isOtaWindowActive())
  {
    WiFi.disconnect(true);
    WiFi.mode(WIFI_OFF);
  }

  return true;
}

void setup()
{
  Serial.begin(115200);
  Serial.setDebugOutput(true);
  delay(3000); // Wait for serial monitor to connect before printing boot messages
  Serial.println("Serial monitor connected (RTC_LOCAL)");
  Serial.println("Boot profile: RTC_LOCAL");

  loadClockConfig(g_config);
  Serial.print("Configured city: ");
  Serial.println(g_config.city);

  if (shouldForceProvisioning())
  {
    Serial.println("Provisioning portal: opening AP");
    // Blocks in captive portal loop until config is applied (device reboots).
    runProvisioningPortalUntilConfigured();
  }

  // Reload config in case portal updated values before reboot/return path.
  loadClockConfig(g_config);

  // Placeholders/empty timezone should never proceed to normal runtime.
  if (!g_config.isValid())
  {
    Serial.println("Config invalid, opening provisioning AP");
    runProvisioningPortalUntilConfigured();
  }

  setupOtaWindow();

  rtc.begin();

  if (!rtc.isrunning())
  {
    // Fallback only if RTC lost state.
    rtc.adjust(DateTime(F(__DATE__), F(__TIME__)));
  }

  if (syncRtcFromInternet())
  {
    lastSyncMs = millis();
  }
  else
  {
    if (WiFi.status() != WL_CONNECTED)
    {
#if PROVISION_ON_CONNECT_FAIL
      Serial.println("Initial WiFi connection failed, opening provisioning AP");
      runProvisioningPortalUntilConfigured();
#else
      Serial.println("Initial WiFi connection failed; provisioning on connect fail is disabled");
#endif
    }
    else
    {
      Serial.println("Initial internet sync failed (API), keeping saved WiFi config");
    }
  }

  // Init display after provisioning so GPIO4 (PSRAM CS) isn't toggled
  // while the provisioning web server is allocating heap memory.
  ClockDisplay.off();

  // BTN_ON is active LOW; use floating input because this line is shared with UART RX.
  pinMode(BTN_ON_PIN, INPUT);
  pinMode(BTN_MODE_PIN, INPUT_PULLUP);

  // LEDs — match RTOS profile boot behavior
  ledcSetup(LED_RED_CH, LED_PWM_FREQ, LED_PWM_BITS);
  ledcSetup(LED_WHITE_CH, LED_PWM_FREQ, LED_PWM_BITS);
  ledcAttachPin(LED_RED_PIN, LED_RED_CH);
  ledcAttachPin(LED_WHITE_PIN, LED_WHITE_CH);
  ledcWrite(LED_WHITE_CH, LED_MAX);
  ledcWrite(LED_RED_CH, LED_MAX);
  delay(3000);
  ledFade(LED_MAX, LED_DIM, 6);
}

void loop()
{
  const unsigned long nowMs = millis();

  // BTN_ON is on GPIO3 (shared with UART RX): avoid edge-only debounce logic,
  // use confirmed raw level + hold tracking for robust behavior.
  static bool sleepHoldTracking = false;
  static unsigned long sleepHoldStartMs = 0;
  // Ensures the same press that caused sleep does not immediately wake again.
  static bool requireReleaseAfterSleep = false;

  const bool btnOnRaw = (digitalRead(BTN_ON_PIN) == LOW);

  // Awake state: require ~500ms hold to enter hibernate.
  if (g_powerState == POWER_AWAKE)
  {
    if (btnOnRaw)
    {
      if (!sleepHoldTracking)
      {
        delay(20);
        if (digitalRead(BTN_ON_PIN) == LOW)
        {
          sleepHoldTracking = true;
          sleepHoldStartMs = nowMs;
        }
      }
      else if (nowMs - sleepHoldStartMs >= 500)
      {
        g_powerState = POWER_HIBERNATE;
        ledFade(LED_DIM, 0, 1);
        ClockDisplay.off();
        ledcWrite(LED_WHITE_CH, 0);
        ledcWrite(LED_RED_CH, 0);
        requireReleaseAfterSleep = true;
        sleepHoldTracking = false;
        delay(20);
        return;
      }
    }
    else
    {
      sleepHoldTracking = false;
    }
  }

  if (g_powerState == POWER_HIBERNATE)
  {
    ClockDisplay.off();
    ledcWrite(LED_WHITE_CH, 0);
    ledcWrite(LED_RED_CH, 0);

    // Gate wake until button is released at least once after entering sleep.
    if (requireReleaseAfterSleep)
    {
      if (!btnOnRaw)
      {
        requireReleaseAfterSleep = false;
      }
      delay(20);
      return;
    }

    // Off state: short press wakes the clock (raw check + confirm for reliability).
    if (btnOnRaw)
    {
      delay(20);
      if (digitalRead(BTN_ON_PIN) != LOW)
      {
        return;
      }

      g_powerState = POWER_AWAKE;
      ledFade(0, LED_DIM, 1);
      delay(180);
    }

    delay(20);
    return;
  }

  // MENU button behavior:
  // short press (<1s): sensor display (if enabled)
  // long press (>=1s): stopwatch
  // held counts 10ms ticks, so held>=100 means about 1 second.
  if (digitalRead(BTN_MODE_PIN) == LOW)
  {
    unsigned long held = 0;
    while (digitalRead(BTN_MODE_PIN) == LOW)
    {
      held++;
      delay(10);
    }

    if (held >= 100)
    {
      runStopwatch();
    }
    else
    {
#if ENABLE_TEMP_SENSOR
      showSensorDisplay();
#endif
    }
  }

  handleOta();
  if (nowMs - lastSyncMs >= syncIntervalMs)
  {
    if (syncRtcFromInternet())
    {
      lastSyncMs = nowMs;
    }
    else
    {
      if (WiFi.status() != WL_CONNECTED)
      {
        // Reboot-time connection failure handles provisioning fallback.
        // During runtime, keep retrying silently to avoid reopening AP.
        Serial.println("WiFi disconnected during runtime; retrying without opening provisioning AP");
      }
      else
      {
        // API/server issue while WiFi is connected - keep running and retry later.
        Serial.println("Internet time sync failed (API), WiFi still connected");
      }
    }
  }

  DateTime now = rtc.now();

  ledcWrite(LED_WHITE_CH, LED_DIM);
  ledcWrite(LED_RED_CH, LED_DIM);

  static unsigned long lastDisplayUpdateMs = 0;
  if (nowMs - lastDisplayUpdateMs >= 200)
  {
    lastDisplayUpdateMs = nowMs;
    showHourMinute(now.hour(), now.minute());
  }

  // Print RTC time once per minute
  static uint8_t lastPrintedMinute = 255;
  if (now.minute() != lastPrintedMinute)
  {
    lastPrintedMinute = now.minute();
    Serial.printf("[RTC]  %02u:%02u:%02u\n", now.hour(), now.minute(), now.second());
  }

  delay(20);
}

#endif

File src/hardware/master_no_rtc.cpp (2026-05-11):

/* Hardware profile: master_no_rtc
 * - No RTC module
 * - Time is fetched from internet API
 * - FreeRTOS tasks: display/button (Core 1), WiFi sync + OTA (Core 0)
 */

#if defined(HARDWARE_MASTER_NO_RTC)

#include <Arduino.h>
#include <WiFi.h>
#include <HTTPClient.h>
#include <WiFiClientSecure.h>
#include <ArduinoJson.h>
#include <ArduinoOTA.h>
#include <nixiDriver.h>
#include <clock_variant_config.h>
#include <clock_provisioning.h>

#ifndef ENABLE_TEMP_SENSOR
#define ENABLE_TEMP_SENSOR 0
#endif

#if ENABLE_TEMP_SENSOR
#include <SHT21.h>
static SHT21 tempSensor;
#endif

#ifndef WIFI_SYNC_SECONDS
#define WIFI_SYNC_SECONDS 3600
#endif

#ifndef ENABLE_OTA
#define ENABLE_OTA 0
#endif

#ifndef OTA_HOSTNAME
#define OTA_HOSTNAME "NixiClock"
#endif

#ifndef OTA_PASSWORD
#define OTA_PASSWORD ""
#endif

#ifndef PROVISION_ON_CONNECT_FAIL
#define PROVISION_ON_CONNECT_FAIL 1
#endif

// ---------------------------------------------------------------------------
// Pin definitions
// ---------------------------------------------------------------------------
#define BTN_ON_PIN    3    // Power/sleep button (active LOW, shared with UART RX)
#define BTN_MODE_PIN  15   // Menu button (active LOW, interrupt-driven)
#define LED_RED_PIN   27
#define LED_WHITE_PIN 26
#define LED_RED_CH    0
#define LED_WHITE_CH  1
#define LED_PWM_FREQ  150000
#define LED_PWM_BITS  10
// Logical full-brightness target used by existing fade/write paths.
#define LED_MAX       1024
#define LED_DIM       70

// ---------------------------------------------------------------------------
// Globals shared between tasks (use volatile / SemaphoreHandle_t for safety)
// ---------------------------------------------------------------------------
nixiDriver ClockDisplay(4, 5, 2, CLOCK_IS_NUMITRON);
ClockConfig g_config;

// Time reference — written by task_wifi, read by task_display
static SemaphoreHandle_t g_timeMutex;
static volatile uint32_t g_syncedSecondsOfDay = 0;
static volatile unsigned long g_syncedMillis   = 0;
static volatile bool          g_hasTime        = false;

// OTA state — only touched by task_wifi
static bool otaInitialized  = false;

const unsigned long syncIntervalMs = WIFI_SYNC_SECONDS * 1000UL;

// Button mode — written by ISR, read by task_display
enum ClockMode { MODE_NORMAL, MODE_ON, MODE_OFF, MODE_FUNCTION };
static volatile ClockMode g_clockMode = MODE_ON;

void IRAM_ATTR isr_btnMode()
{
  g_clockMode = MODE_FUNCTION;
}

// ---------------------------------------------------------------------------
// Helper: LED fade
// ---------------------------------------------------------------------------
static void ledFade(int from, int to, int stepDelayMs)
{
  if (from <= to)
  {
    for (int i = from; i <= to; i++)
    {
      ledcWrite(LED_WHITE_CH, i);
      ledcWrite(LED_RED_CH,   i);
      vTaskDelay(pdMS_TO_TICKS(stepDelayMs));
    }
  }
  else
  {
    for (int i = from; i >= to; i--)
    {
      ledcWrite(LED_WHITE_CH, i);
      ledcWrite(LED_RED_CH,   i);
      vTaskDelay(pdMS_TO_TICKS(stepDelayMs));
    }
  }
}

// ---------------------------------------------------------------------------
// Helper: display
// ---------------------------------------------------------------------------
static void showHourMinute(uint8_t hour, uint8_t minute)
{
  ClockDisplay.writeSegment(hour   / 10, SEGMENT_1);
  ClockDisplay.writeSegment(hour   % 10, SEGMENT_2);
  ClockDisplay.writeSegment(minute / 10, SEGMENT_3);
  ClockDisplay.writeSegment(minute % 10, SEGMENT_4);
}

// ---------------------------------------------------------------------------
// Stopwatch (runs inside task_display)
// ---------------------------------------------------------------------------
static void runStopwatch()
{
  ledcWrite(LED_RED_CH, 0);
  int sec = 0, s = 0, m = 0;
  uint8_t togW = 1, togR = 0;
  int count = 0;

  for (;;)
  {
    if (m >= 60 || digitalRead(BTN_ON_PIN) == LOW)
    {
      g_clockMode = MODE_NORMAL;
      vTaskDelay(pdMS_TO_TICKS(700));
      break;
    }
    if (count % 100 == 0)
    {
      ledcWrite(LED_WHITE_CH, togR * LED_MAX);
      ledcWrite(LED_RED_CH,   togW * LED_MAX);
      m = sec / 60;
      s = sec - m * 60;
      ClockDisplay.writeSegment(m / 10, SEGMENT_1);
      ClockDisplay.writeSegment(m % 10, SEGMENT_2);
      ClockDisplay.writeSegment(s / 10, SEGMENT_3);
      ClockDisplay.writeSegment(s % 10, SEGMENT_4);
      sec++;
      togW = !togW;
      togR = !togR;
    }
    count++;
    vTaskDelay(pdMS_TO_TICKS(10));
  }
}

// ---------------------------------------------------------------------------
// Sensor display (runs inside task_display, only when ENABLE_TEMP_SENSOR)
// ---------------------------------------------------------------------------
#if ENABLE_TEMP_SENSOR
static void showSensorDisplay()
{
  const float rawT = tempSensor.getTemperature();
  const float rawH = tempSensor.getHumidity();
  const int8_t  t  = (int8_t)(rawT >= 0 ? rawT + 0.5f : rawT - 0.5f);
  const uint8_t h  = (uint8_t)(rawH + 0.5f);
  const uint8_t at = (uint8_t)(t < 0 ? -t : t);

  ledcWrite(LED_WHITE_CH, LED_MAX);
  ledcWrite(LED_RED_CH, t < 0 ? 0 : LED_MAX);

  ClockDisplay.writeSegment(t < 0 ? 0 : 10, SEGMENT_1);
  ClockDisplay.writeSegment(t < 0 ? 0 : 10, SEGMENT_2);
  ClockDisplay.writeSegment(at / 10, SEGMENT_3);
  ClockDisplay.writeSegment(at % 10, SEGMENT_4);
  vTaskDelay(pdMS_TO_TICKS(1500));

  ClockDisplay.writeSegment(10,     SEGMENT_1);
  ClockDisplay.writeSegment(10,     SEGMENT_2);
  ClockDisplay.writeSegment(h / 10, SEGMENT_3);
  ClockDisplay.writeSegment(h % 10, SEGMENT_4);
  ledcWrite(LED_WHITE_CH, LED_MAX);
  ledcWrite(LED_RED_CH,   0);
  vTaskDelay(pdMS_TO_TICKS(1500));

  Serial.printf("[SENSOR] Temp: %d C  Humidity: %u%%\n", t, h);
  g_clockMode = MODE_NORMAL;
}
#endif

// ---------------------------------------------------------------------------
// OTA helpers (used by task_wifi)
// ---------------------------------------------------------------------------
static bool isOtaWindowActive()
{
#if ENABLE_OTA
  return otaInitialized;
#else
  return false;
#endif
}

static void setupOtaWindow()
{
#if ENABLE_OTA
  ArduinoOTA.setHostname(OTA_HOSTNAME);
  if (strlen(OTA_PASSWORD) > 0)
    ArduinoOTA.setPassword(OTA_PASSWORD);
  ArduinoOTA.onStart([]() { Serial.println("[OTA] Update started"); });
  ArduinoOTA.onEnd([]()   { Serial.println("[OTA] Update finished"); });
  ArduinoOTA.onError([](ota_error_t error) {
    Serial.printf("[OTA] Error %d\n", (int)error);
  });
  ArduinoOTA.begin();
  otaInitialized = true;
  Serial.printf("[OTA] Ready at %s (always on)\n",
                WiFi.localIP().toString().c_str());
#endif
}
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

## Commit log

2019-12-23 added temperature from api
2019-12-25 added correct ssid and psw
    [main.cpp]
2019-12-28 correct temp and pres update
    [main.cpp]
2019-12-30 correct 0 error on temp
    [main.cpp]
2020-01-12 added pcb
    [3.3V_StepDown.brd, 3.3V_StepDown.sch, ESP32.brd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]
2020-01-16 added case Folder for lasercutter
    [nixiBottom.dxf, nixiTop.dxf]
2020-01-19 added RTC, SHT21, LED Pins support
2026-05-03 Refactor clock provisioning and synchronization logic
    - Removed the `debug-deep-sleep` skill documentation as it is no longer needed.
    - Updated `flash-and-monitor` skill to reflect changes in configuration parameters and diagnostics.
    - Enhanced `config.env.example` with new parameters for WiFi provisioning and time synchronization.
    - Modified `read_config_env.py` to support legacy `.env` file and ensure proper string handling for configuration values.
    - Introduced `clock_provisioning.h` and `clock_provisioning.cpp` to manage WiFi configuration via a captive portal.
    - Updated `master_no_rtc.cpp` and `rtc_local.cpp` to utilize the new provisioning logic and handle time synchronization more rob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
    [clock_provisioning.cpp, master_no_rtc.cpp, rtc_local.cpp]
2026-05-11 Refactor RTC and Nixie Clock Functionality
    - Enhanced RTC functionality in rtc_local.cpp with improved time synchronization and added temperature sensor support.
    - Introduced stopwatch feature and refined power management states for better user experience.
    - Updated main.cpp to remove legacy code and streamline setup and loop functions, delegating functionality to hardware-specific profiles.
    - Improved nixiDriver.cpp with additional comments for clarity on Nixie and Numitron segment encoding.
    - Removed unused variables and optimized code structure for maintainability.
